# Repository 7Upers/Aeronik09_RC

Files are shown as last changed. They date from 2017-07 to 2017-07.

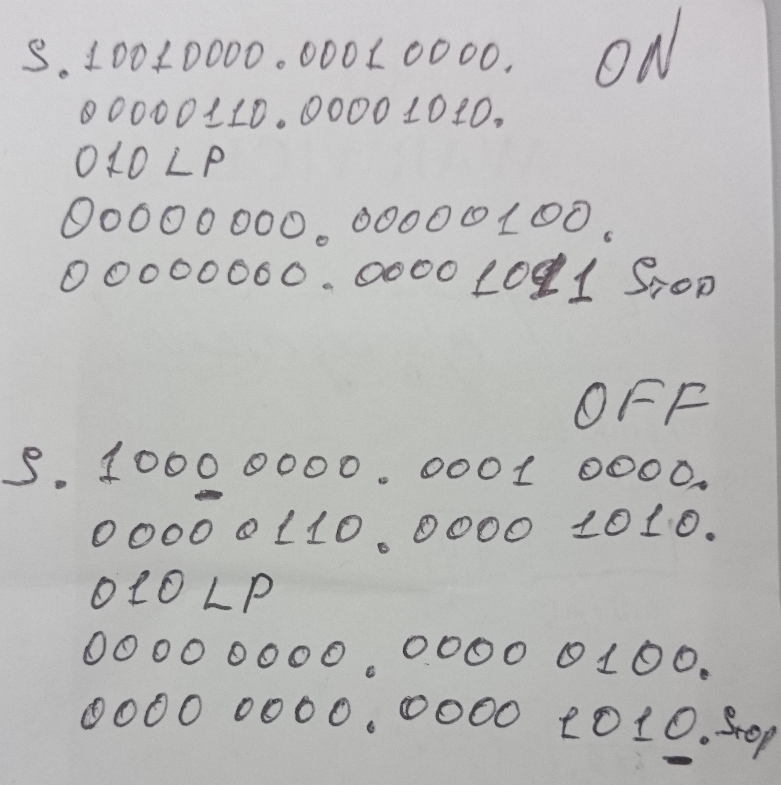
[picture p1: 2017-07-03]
img/cmds.jpg

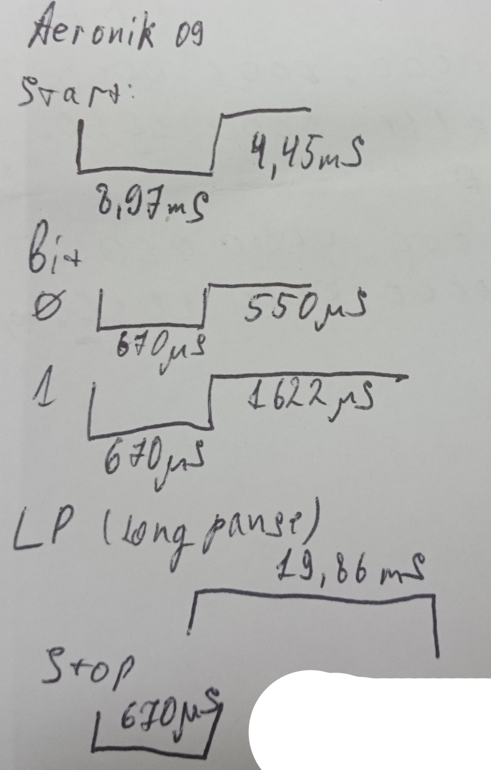
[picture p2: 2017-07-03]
img/proto.jpg

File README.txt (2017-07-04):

Aeronik09_RC

Этот проект разрабатывается для автоматизированного управления сплит системой Aeronik модель 09 2012 года MCU - ATMega328p

1.    Измерение температуры в области устройства с помощью датчика DS18B20 шина 1-wire
2.    При превышении температуры порога1 - включение сплит-системы, по средствам посылки команды включения через инфракрасный канал (несущая 38kHz генерируется с помощью аппаратного ШИМ в режиме CTC c фиксированной скважностью 50%), сигнал модулируется путем подключения и отключения счетчика (на котором реализована генерация несущей) к источнику тактирования, при передаче низкого уровня - подключается к основному тактовому генератору 16MHz с делителем на 8, при передаче высокого уровня - отключается от источника тактирования.
3.    При понижении температуры ниже порога2 - выключение сплит-системы, через IR канал
4.    Также необходим контроль по максимальному времени работы сплит-системы, по максимальному времени ожидания при не достижении порога2.
5.    IR команды посылаются 2 раза через интервал (random*10сек), что-бы избежать искажения команды в результате интерференции сигнала с другим IR излучателем или искажения при переотражении.

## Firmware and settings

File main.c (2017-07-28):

#include <stdio.h>
#include <stdlib.h>
#include <avr/io.h>
#include <util/delay.h>
#include <string.h>

#include "lib/uart.h"
#include "lib/ds18b20.h"
#include "lib/aeronik09.h"

#define LED PB5
#define TOMAX 240 //period of turn on air conditioner, 1 time peer 40min
#define TWMAX 120 //max time of work air conditioner 20min
#define TCMAX 26 //max temperature of celsium degrees, after thet need turn on air conditioner
#define TCMIN 23 //min temperature of celsium degrees, after thet need turn off air conditioner

int main (void)
{
	uart_init(MYUBRR);

	//sys led
	DDRB |= (1<<LED);
	PORTD &= ~(1<<LED);

	AC_INIT;

	uint8_t state = 0; //air condition 0 - turned off, 1 - turned on
	unsigned long int timer_o = TOMAX; //frequency of turn on control timer
	unsigned long int timer_w = 0; //work timer
	double temp = 0; //current temperature
	uint8_t skip[8] = {0, 0, 0, 0, 0, 0, 0, 0};

	while (1)
	{
		ds18b20_startconvert(skip);
		temp = ds18b20_getsometemp();
		printf("Themperature= %3.2lf deg C (o=%ld, w=%ld)\r\n", temp, timer_o, timer_w);

		//Включаемся не чаще 1 раза в 40мин.
		if (( timer_o > TOMAX )&&( state == 0 ))
		{
			if ( temp > TCMAX )
			{
				AC_ON;
				_delay_ms(1000);
				AC_ON;
				printf("Aeronik09 ON\r\n");
				PORTB |= _BV(LED);
				timer_o = 0;
				state = 1;
			}
		}

		if ( state == 1 )
		{
			if (( timer_w > TWMAX )||( temp < TCMIN ))
			{
				AC_OFF;
				_delay_ms(1000);
				AC_OFF;
				printf("Aeronik09 OFF ");
				if ( temp < TCMIN )
				{
					printf(" by Temperature exceed\r\n");
				}
				else
				{
					printf(" by Timer exceed\r\n");
				}
				PORTB &= ~_BV(LED);
				timer_w = 0;
				state = 0;
			}
			timer_w++;
		}

		timer_o++;
		_delay_ms(4000);
		//in real each cycle will be freq 1Hz (1time peer sec)
	}
}

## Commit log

2017-07-03 add temp sensor
2017-07-04 fix LONG PAUSE half byte, correct timing
    [main.c]
2017-07-04 fix temperature data show, and add termostat alhoritm
    [main.c]
2017-07-04 aeronik specific code to lib, fix turned on irled after sent
    [main.c]
2017-07-04 add some defines, modify timers work algoritm
2017-07-05 added schematic
    [ir_transmitter.fzz]
2017-07-05 fix schematic
    [ir_transmitter.fzz]
2017-07-05 add principal schematic
2017-07-05 fix hardware
    [ir_transmitter.fzz]
